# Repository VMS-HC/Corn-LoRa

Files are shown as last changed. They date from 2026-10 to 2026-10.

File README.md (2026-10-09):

<p align="left">
  Moving Rainbow Gradient Text
</p>
A not so basic electronic project... This is a LoRa Board which is great for meshtastic but not great for my sanity when routing! This has a SX1262 radio chip and uses a RP2040 for the microcontroller along with a crystal oscillator for the RP2040 like any normal dev board. Corn LoRa also includes a *0900FM15D0039* as a IPD (integrated passive device) by Johanson which controls the balun and filtering (868-915MHz, may be different footprint) To switch between TX and RX, it uses an RF switch, controlled by DIO2; along with a PE4259 for a 2 channel switcher (as mentioned above!). It also uses a bulky non-standard Conn for an antenna! 
Ty for looking and have a good day! <3!
# Corn-LoRa PCB photo!
 3D Render photo!
 Schematic!

    

## FAQ

#### BOM?

There are 2 BOM technically one has the LCSC part numbers and the others is a quote from LCSC with links to parts too!

#### Is this good for beginners?

Yes and no, if you know EDA/Kicad basics and could make a dev board without trouble you should be able to make this!

#### How many layers is the PCB?

This is a 4 layer PCB with a Earth layer and a +3V3 layer!

#### Can I contribute?

YES YOU CAN!!!! Take a peek at the Contributing section for a better guide on contributing!

## Authors

- [@bobert3d](https://www.github.com/Bobert3D)

- [@vms-hc](https://www.github.com/VMS-HC)

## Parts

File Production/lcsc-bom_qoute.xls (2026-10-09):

Corn LoRa |  |  |  |  |  |  |  |  |  | LCSC BOM Quotation
 |  |  |  |  |  |  |  |  |  | BOM Date Created：09/10/26 01:26:32 |  |  |  | BOM Export Date: 09/10/26 22:58:34 |  |  |  | The matching result is a real-time query result, availability and prices may fluctuate. Backorder items are estimated prices for your reference, please submit "Create Quote" to get the real price. All information is provided "as is" and is subject to change without notice. Any use made of the information provided is without recourse to LCSC and at the user's risk.
 |  |  |  |  |  |  |  |  |  | EST TOTAL :$22.09 |  |  |  | Website：https://www.lcsc.com/bom | https://www.lcsc.com/bom | https://www.lcsc.com/bom | https://www.lcsc.com/bom
Uploaded data |  |  |  |  |  |  |  |  |  | LCSC Matching Results
LCSC# | Mfr. | Mrf# | Description | Package | Value | Customer Part Number | Quantity | Target Price(USD) | Target Lead Time(Business Days) | Mrf# | Mfr. | Order Qty. | Unit Price(USD) | Ext.Price(USD) | LCSC# | Package | Min | Mult | SPQ | Availability | Stock Status | Customer Notes | Description | Matched status | Product Link
LCSC C276421 |  |  |  | Crystal_SMD_Abracon_ABM8G-4Pin_3.2x2.5mm |  | - | 1 |  |  | ABM8G-12.000MHZ-B4Y-T | ABRACON | 1 | 0.4560 | 0.46 | C276421 | SMD3225-4P | 1 | 1 | 1000 | 3622 | In Stock |  | Crystal 12MHz ±30ppm 10pF 120Ω SMD3225-4P | Partial Matches | https://www.lcsc.com/product-detail/C276421.html
LCSC |  |  |  | PinSocket_1x01_P2.54mm_Vertical |  |  | 1 |  |  | -(The data has been deleted.) | - | - | - | - | - | - | - | - | - | - | - | - | - | -
LCSC C2689642 |  |  |  | SW_Tactile_SPST_NO_Straight_CK_PTS636Sx25SMTRLFS |  | - | 1 |  |  | PTS636SK25SMTRLFS | C&K | 5 | 0.3565 | 1.78 | C2689642 | SMD,6x3.5mm | 5 | 5 | 3000 | 3045 | In Stock |  | Tactile Switch SPST-NO 250gf Gull Wing Surface Mount | Partial Matches | https://www.lcsc.com/product-detail/C2689642.html
LCSC C3951825 |  |  |  | R_0402_1005Metric |  | - | 2 |  |  | CRCW040227R4FKED | VISHAY | 50 | 0.0104 | 0.52 | C3951825 | 0402 | 50 | 50 | 10000 | 9650 | In Stock |  | 63mW 27.4Ω Thick Film Resistor ±100ppm/℃ ±1% 0402 Chip Resistor - Surface Mount RoHS | Partial Matches | https://www.lcsc.com/product-detail/C3951825.html
LCSC C327287 |  |  |  | C_0402_1005Metric |  | - | 3 |  |  | CC0402BRNPO9BN3R3 | YAGEO | 50 | 0.0084 | 0.42 | C327287 | 0402 | 50 | 50 | 10000 | 158500 | In Stock |  | 3.3pF 50V Ceramic Capacitor NP0 0402 | Partial Matches | https://www.lcsc.com/product-detail/C327287.html
LCSC C1525 |  |  |  | C_0402_1005Metric |  | - | 13 |  |  | CL05B104KO5NNNC | Samsung Electro-Mechanics | 100 | 0.0046 | 0.46 | C1525 | 0402 | 100 | 100 | 10000 | 102600 | In Stock |  | 100nF ±10% 16V Ceramic Capacitor X7R 0402 | Partial Matches | https://www.lcsc.com/product-detail/C1525.html
LCSC C60490 |  |  |  | R_0402_1005Metric |  | - | 1 |  |  | RC0402FR-0710KL | YAGEO | 100 | 0.0023 | 0.23 | C60490 | 0402 | 100 | 100 | 10000 | 4624300 | In Stock |  | 62.5mW 10kΩ 50V Thick Film Resistor ±100ppm/℃ ±1% 0402 Chip Resistor - Surface Mount RoHS | Partial Matches | https://www.lcsc.com/product-detail/C60490.html
LCSC C408132 |  |  |  | C_0402_1005Metric |  | - | 2 |  |  | GRM155R61A106ME11D | muRata | 20 | 0.0455 | 0.91 | C408132 | 0402 | 20 | 20 | 10000 | 280000 | In Stock |  | 10uF ±20% 10V Ceramic Capacitor X5R 0402 | Partial Matches | https://www.lcsc.com/product-detail/C408132.html
LCSC C191341 |  |  |  | QFN-24-1EP_4x4mm_P0.5mm_EP2.6x2.6mm |  | - | 1 |  |  | SX1262IMLTRT | SEMTECH | 1 | 3.2219 | 3.22 | C191341 | QFN-24-EP(4x4) | 1 | 1 | 3000 | 13955 | In Stock |  | 300Kbps -148dBm ISM 150MHz~960MHz 1.8V~3.7V QFN-24-EP(4x4) RF Transceiver ICs RoHS | Partial Matches | https://www.lcsc.com/product-detail/C191341.html
LCSC C2988369 |  |  |  | USB_C_Receptacle_GCT_USB4105-xx-A_16P_TopMnt_Horizontal |  | - | 1 |  |  | GT-USB-7010ASV | G-Switch | 5 | 0.0839 | 0.42 | C2988369 | SMD | 5 | 5 | 1000 | 87620 | In Stock |  | USB-C (USB TYPE-C) Receptacle Connector 16 Position Surface Mount, Right Angle | Partial Matches | https://www.lcsc.com/product-detail/C2988369.html
LCSC C106235 |  |  |  | R_0402_1005Metric |  | - | 2 |  |  | RC0402FR-071KL | YAGEO | 100 | 0.0038 | 0.38 | C106235 | 0402 | 100 | 100 | 10000 | 1131800 | In Stock |  | 1kΩ 62.5mW 50V Thick Film Resistor ±100ppm/℃ ±1% 0402 Chip Resistor - Surface Mount RoHS | Partial Matches | https://www.lcsc.com/product-detail/C106235.html
LCSC C383402 |  |  |  | L_0805_2012Metric_Pad1.15x1.40mm_HandSolder |  | - | 1 |  |  | MLZ2012M150WT000 | TDK | 10 | 0.0745 | 0.75 | C383402 | 0805 | 10 | 10 | 2000 | 32740 | In Stock |  | 250mA 15uH ±20% 120mA 950mΩ Multilayer inductor 0805 Fixed Inductors RoHS | Partial Matches | https://www.lcsc.com/product-detail/C383402.html
LCSC C105872 |  |  |  | R_0402_1005Metric |  | - | 2 |  |  | RC0402FR-075K1L | YAGEO | 100 | 0.0025 | 0.25 | C105872 | 0402 | 100 | 100 | 10000 | 2123800 | In Stock |  | 5.1kΩ 62.5mW 50V Thick Film Resistor ±100ppm/℃ ±1% 0402 Chip Resistor - Surface Mount RoHS | Partial Matches | https://www.lcsc.com/product-detail/C105872.html
LCSC C29266 |  |  |  | C_0402_1005Metric |  | - | 2 |  |  | CL05A105KO5NNNC | Samsung Electro-Mechanics | 50 | 0.0076 | 0.38 | C29266 | 0402 | 50 | 50 | 10000 | 1336100 | In Stock |  | 1uF ±10% 16V Ceramic Capacitor X5R 0402 | Partial Matches | https://www.lcsc.com/product-detail/C29266.html
LCSC C113767 |  |  |  | SOIC-8_5.3x5.3mm_P1.27mm |  | - | 1 |  |  | W25Q128JVSIQ | Winbond | 1 | 2.5196 | 2.52 | C113767 | SOIC-8-208mil | 1 | 1 | 90 | 7241 | In Stock |  | 128Mbit 2.7V~3.6V 133MHz SPI SOIC-8-208mil Memory RoHS | Partial Matches | https://www.lcsc.com/product-detail/C113767.html
LCSC C23380830 |  |  |  | SOT-23-5 |  | - | 1 |  |  | AP2112K-3.3TRG1 | TECH PUBLIC | 5 | 0.1113 | 0.56 | C23380830 | SOT-23-5 | 5 | 5 | 3000 | 2250 | In Stock |  | 3.3V Positive Fixed SOT-23-5 Voltage Regulators - Linear, Low Drop Out (LDO) Regulators | Partial Matches | https://www.lcsc.com/product-detail/C23380830.html
LCSC C470892 |  |  |  | SOT-363_SC-70-6 |  | - | 1 |  |  | PE4259-63 | pSemi | 1 | 1.1563 | 1.16 | C470892 | SC-70-6 | 1 | 1 | 3000 | 3498 | In Stock |  | 10MHz~3GHz SC-70-6 RF Switches RoHS | Partial Matches | https://www.lcsc.com/product-detail/C470892.html
LCSC C441742 |  |  |  | C_0402_1005Metric |  | - | 2 |  |  | GJM1555C1H150FB01D | muRata | 50 | 0.0241 | 1.21 | C441742 | 0402 | 50 | 50 | 10000 | 298650 | In Stock |  | 15pF ±1% 50V Ceramic Capacitor C0G 0402 | Partial Matches | https://www.lcsc.com/product-detail/C441742.html
LCSC C880605 |  |  |  | C_0402_1005Metric |  | - | 2 |  |  | TCC0402X7R473K500AT | CCTC | 50 | 0.0029 | 0.15 | C880605 | 0402 | 50 | 50 | 10000 | 1505350 | In Stock |  | 47nF ±10% 50V Ceramic Capacitor X7R 0402 | Partial Matches | https://www.lcsc.com/product-detail/C880605.html
LCSC C85815 |  |  |  | L_0402_1005Metric |  | - | 1 |  |  | BLM15AX102SN1D | muRata | 100 | 0.0112 | 1.12 | C85815 | 0402 | 100 | 100 | 10000 | 98600 | In Stock |  | 1kΩ@100MHz 1 Line Ferrite Bead 0402 350mA 490mΩ | Partial Matches | https://www.lcsc.com/product-detail/C85815.html
LCSC C7434807 |  |  |  | Balun_Johanson_0900FM15K0039 |  | - | 1 |  |  | 0900FM15K0039001E | Johanson Dielectrics | 1 | 0.9819 | 0.98 | C7434807 | 0805 | 1 | 1 | 4000 | 382 | In Stock |  | 1.1dB 862MHz~928MHz 0805 Ceramic Filters RoHS | Partial Matches | https://www.lcsc.com/product-detail/C7434807.html
LCSC C14442 |  |  |  | C_0402_1005Metric |  | - | 1 |  |  | CL05B102KB5NNNC | Samsung Electro-Mechanics | 100 | 0.0044 | 0.44 | C14442 | 0402 | 100 | 100 | 10000 | 1821700 | In Stock |  | 1nF ±10% 50V Ceramic Capacitor X7R 0402 | Partial Matches | https://www.lcsc.com/product-detail/C14442.html
LCSC C2040 |  |  |  | QFN-56-1EP_7x7mm_P0.4mm_EP3.2x3.2mm |  | - | 1 |  |  | RP2040 | Raspberry Pi | 1 | 0.9975 | 1.00 | C2040 | LQFN-56(7x7) | 1 | 1 | 3400 | 53257 | In Stock |  | ARM Cortex-M0+ 32 Bit 133MHz LQFN-56(7x7) Microcontrollers | Partial Matches | https://www.lcsc.com/product-detail/C2040.html
LCSC C2689642 |  |  |  | SW_Tactile_SPST_NO_Straight_CK_PTS636Sx25SMTRLFS |  |  | 1 |  |  | -(The data has been deleted.) | - | - | - | - | - | - | - | - | - | - | - | - | - | -
LCSC C162547 |  |  |  | L_0402_1005Metric |  | - | 1 |  |  | LQG15HS9N1J02D | muRata | 50 | 0.0190 | 0.95 | C162547 | 0402 | 50 | 50 | 10000 | 462950 | In Stock |  | 500mA 9.1nH ±5% 260mΩ Multilayer inductor 0402 Fixed Inductors RoHS | Partial Matches | https://www.lcsc.com/product-detail/C162547.html
LCSC C7275126 |  |  |  | Crystal_SMD_3225-4Pin_3.2x2.5mm |  | - | 1 |  |  | HY32MSMD3225EB1R30 | Huiyuan crystal | 10 | 0.0663 | 0.66 | C7275126 | SMD3225-4P | 10 | 10 | 3000 | 2440 | In Stock |  | Crystal 32MHz 10pF 40Ω SMD3225-4P | Partial Matches | https://www.lcsc.com/product-detail/C7275126.html
LCSC C2906884 |  |  |  | R_0402_1005Metric |  | - | 1 |  |  | FRC0402J101 TS | FOJAN | 100 | 0.0012 | 0.12 | C2906884 | 0402 | 100 | 100 | 10000 | 3792600 | In Stock |  | 100Ω ±5% 62.5mW 0402 Thick Film Resistor | Partial Matches | https://www.lcsc.com/product-detail/C2906884.html
LCSC C106223 |  |  |  | C_0402_1005Metric |  | - | 1 |  |  | CC0402JRNPO9BN390 | YAGEO | 100 | 0.0047 | 0.47 | C106223 | 0402 | 100 | 100 | 10000 | 195000 | In Stock |  | 39pF ±5% 50V Ceramic Capacitor NP0 0402 | Partial Matches | https://www.lcsc.com/product-detail/C106223.html
LCSC C47339 |  |  |  | C_0402_1005Metric |  | - | 1 |  |  | CL05A474KP5NNNC | Samsung Electro-Mechanics | 50 | 0.0113 | 0.57 | C47339 | 0402 | 50 | 50 | 10000 | 173350 | In Stock |  | 470nF ±10% 10V Ceramic Capacitor X5R 0402 | Partial Matches | https://www.lcsc.com/product-detail/C47339.html
TBD |  |  |  | U.FL_Molex_MCRF_73412-0110_Vertical |  |  | 1 |  |  | -(The data has been deleted.) | - | - | - | - | - | - | - | - | - | - | - | - | - | -

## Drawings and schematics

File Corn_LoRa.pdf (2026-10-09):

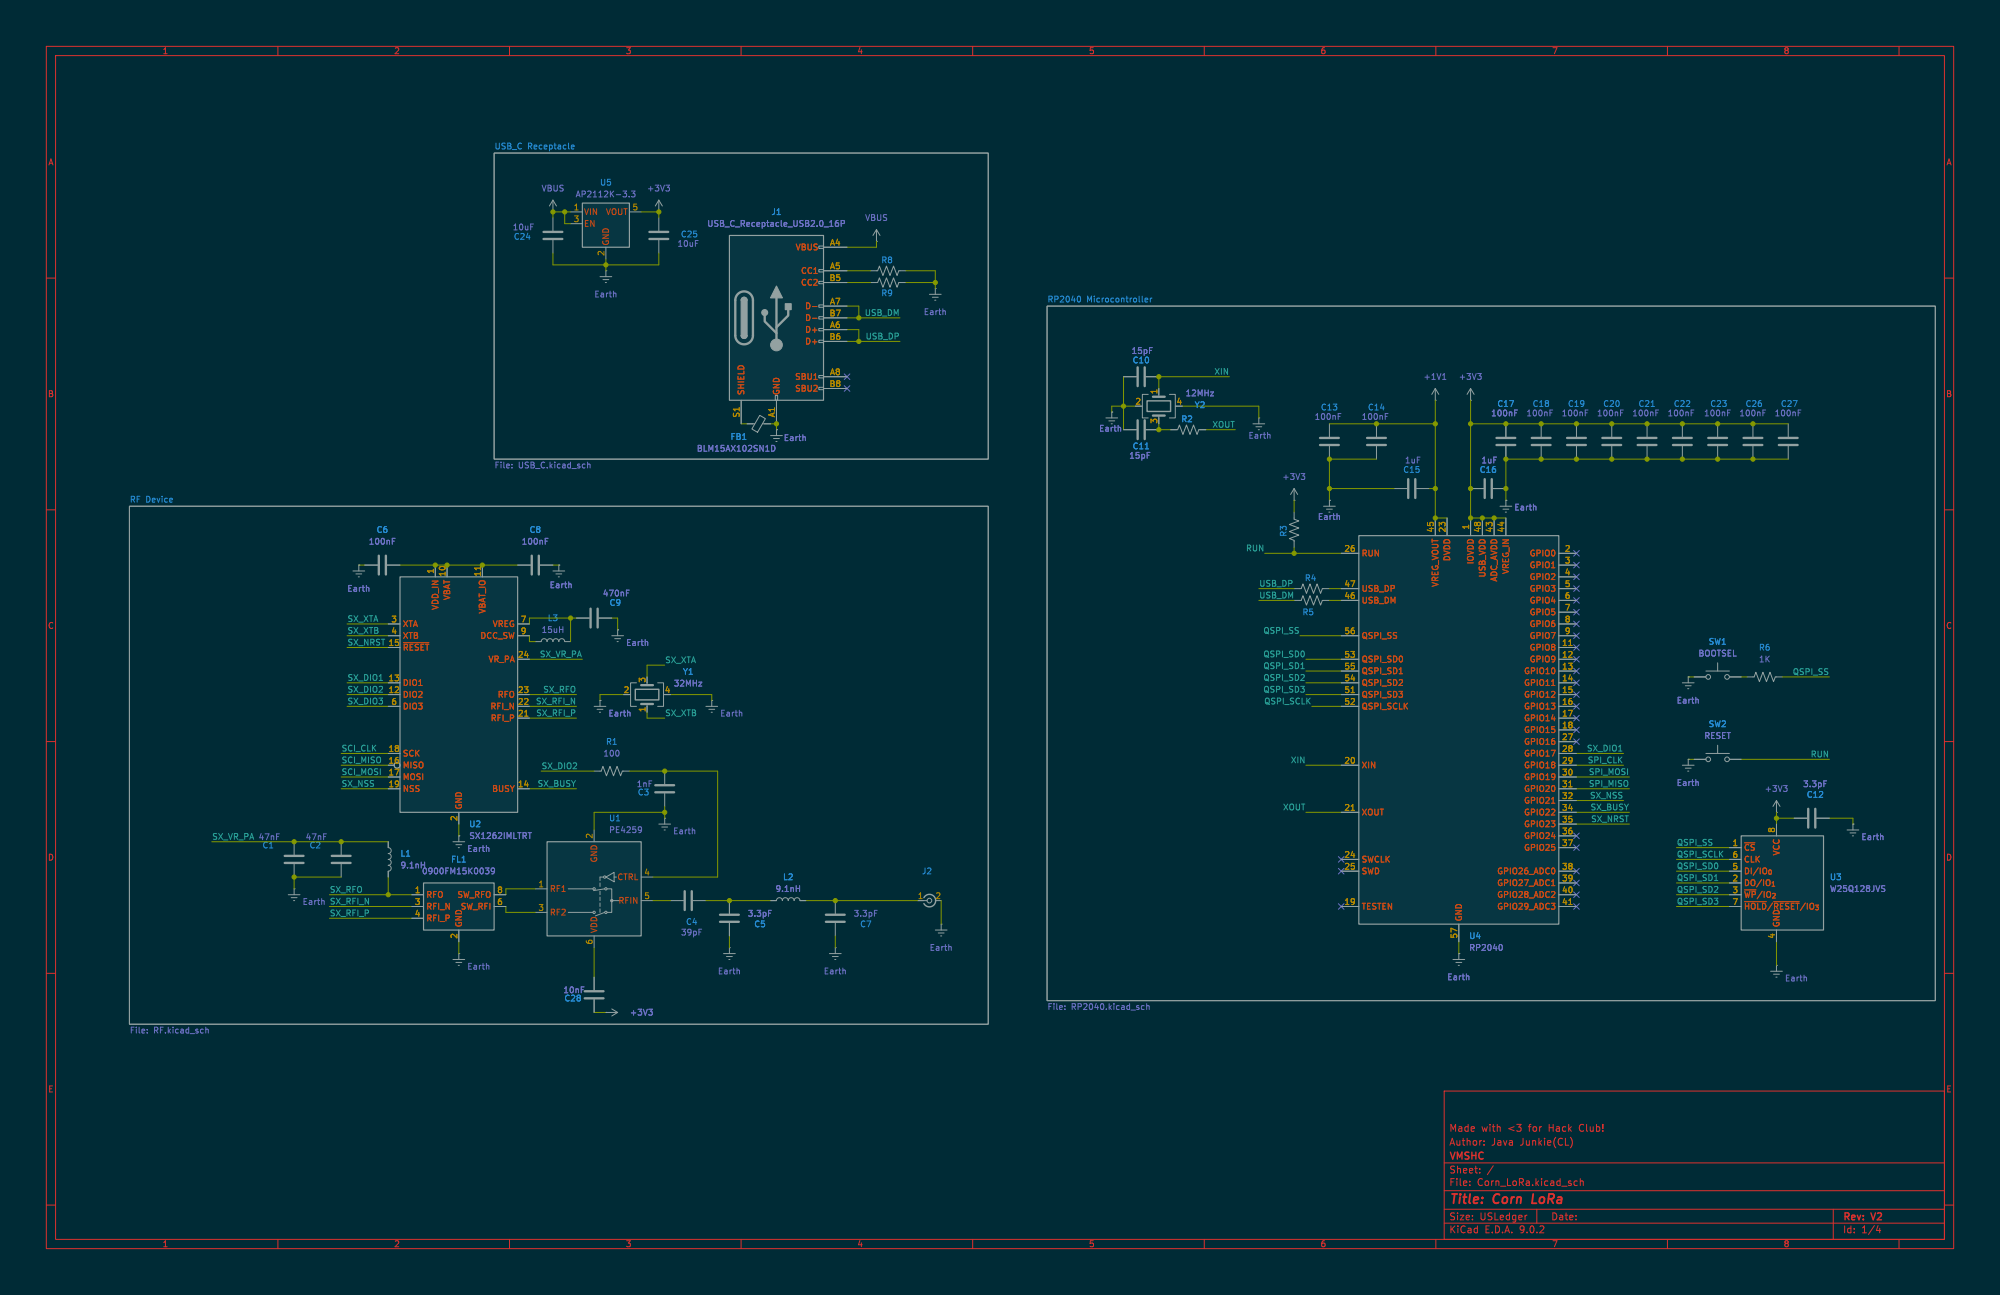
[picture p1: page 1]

1 USB_VDD 48 ADC_AVDD 43 VREG_IN 44 GPIO0 2 GPIO1 3 GPIO2 4 GPIO3 5 GPIO4 6 GPIO5 7 GPIO6 8 GPIO7 9 GPIO8 11 GPIO9 12 GPIO10 13 GPIO11 14 GPIO12 15 GPIO13 16 GPIO14 17 GPIO15 18 GPIO16 27 GPIO17 28 GPIO18 29 GPIO19 30 GPIO20 31 GPIO21 32 GPIO22 34 GPIO23 35 GPIO24 36 GPIO25 37 GPIO26_ADC0 38 GPIO27_ADC1 39 GPIO28_ADC2 40 GPIO29_ADC3 41 Earth Earth SW2 RESET SW1 BOOTSEL Earth C10

2 SW_RFO 8 SW_RFI 6 U2SX1262IMLTRT XTA 3 XTB 4 ~{RESET} 15 DIO1 13 DIO2 12 DIO3 6 SCK 18 MISO 16 MOSI 17 NSS 19 VDD_IN

Id: 1/4 Title: Corn LoRa

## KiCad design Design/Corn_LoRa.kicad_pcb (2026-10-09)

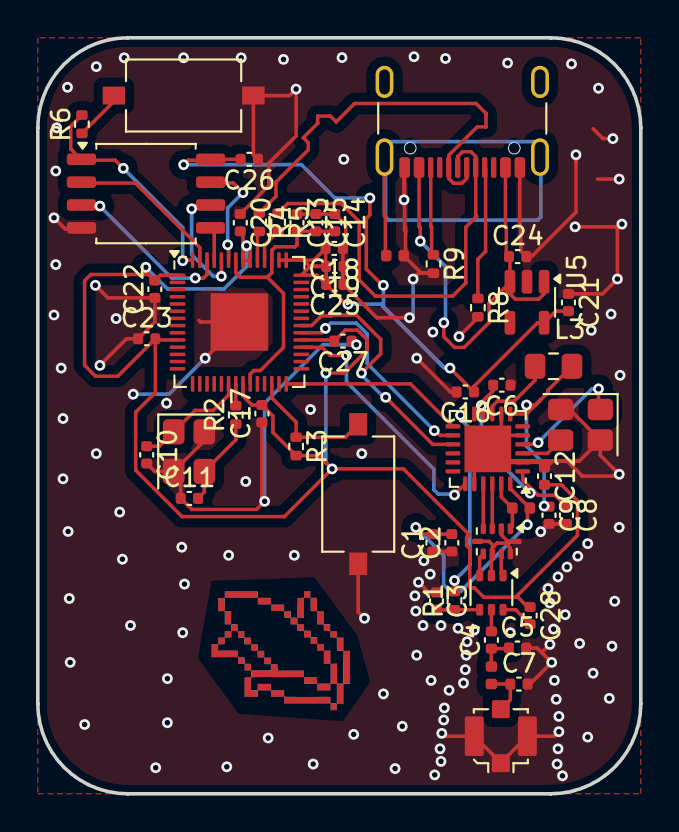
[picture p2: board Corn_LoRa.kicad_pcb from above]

Board: 4 copper layers, 33.5 x 42.0 mm, 52 parts (0 on the bottom side), 43 nets.

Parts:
C1, C2: 47nF; C_0402_1005Metric
C3: 1nF; C_0402_1005Metric
C4: 39pF; C_0402_1005Metric
C5, C7, C12: 3.3pF; C_0402_1005Metric
C6, C8, C13, C14, C17, C18, C19, C20, C21, C22, C23, C26, C27: 100nF; C_0402_1005Metric
C9: 470nF; C_0402_1005Metric
C10, C11: 15pF; C_0402_1005Metric
C15, C16: 1uF; C_0402_1005Metric
C24, C25: 10uF; C_0402_1005Metric
C28: 10nF; C_0402_1005Metric
FB1: BLM15AX102SN1D; L_0402_1005Metric
FL1: 0900FM15K0039; Balun_Johanson_0900FM15K0039
J1: USB_C_Receptacle_USB2.0_16P; USB_C_Receptacle_GCT_USB4105-xx-A_16P_TopMnt_Horizontal
J2: Conn_Coaxial_Small; U.FL_Molex_MCRF_73412-0110_Vertical
L1, L2: 9.1nH; L_0402_1005Metric
L3: 15uH; L_0805_2012Metric_Pad1.15x1.40mm_HandSolder
R1: 100; R_0402_1005Metric
R2, R6: 1K; R_0402_1005Metric
R3: 10K; R_0402_1005Metric
R4, R5: 27.4; R_0402_1005Metric
R8, R9: 5.1K; R_0402_1005Metric
SW1: BOOTSEL; SW_Tactile_SPST_NO_Straight_CK_PTS636Sx25SMTRLFS
SW2: RESET; SW_Tactile_SPST_NO_Straight_CK_PTS636Sx25SMTRLFS
U1: PE4259; SOT-363_SC-70-6
U2: SX1262IMLTRT; QFN-24-1EP_4x4mm_P0.5mm_EP2.6x2.6mm
U3: W25Q128JVS; SOIC-8_5.3x5.3mm_P1.27mm
U4: RP2040; QFN-56-1EP_7x7mm_P0.4mm_EP3.2x3.2mm
U5: AP2112K-3.3; SOT-23-5
Y1: 32MHz; Crystal_SMD_3225-4Pin_3.2x2.5mm
Y2: 12MHz; Crystal_SMD_Abracon_ABM8G-4Pin_3.2x2.5mm

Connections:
+1V1: C13.2, C14.2, C15.2, U4.23 (DVDD), U4.45 (VREG_VOUT), U4.50 (DVDD)
+3V3: C12.2, C16.1, C17.2, C18.2, C19.2, C20.2, C21.2, C22.2, C23.2, C25.2, C26.2, C27.2, C28.1, R3.2, U3.8 (VCC), U4.1 (IOVDD), U4.10 (IOVDD), U4.22 (IOVDD), U4.33 (IOVDD), U4.42 (IOVDD), U4.43 (ADC_AVDD), U4.44 (VREG_IN), U4.48 (USB_VDD), U4.49 (IOVDD), U5.5 (VOUT)
/QSPI_SCLK: U3.6 (CLK), U4.52 (QSPI_SCLK)
/QSPI_SD0: U3.5 (DI/IO_{0}), U4.53 (QSPI_SD0)
/QSPI_SD1: U3.2 (DO/IO_{1}), U4.55 (QSPI_SD1)
/QSPI_SD2: U3.3 (~WP/IO_{2}), U4.54 (QSPI_SD2)
/QSPI_SD3: U3.7 (~HOLD/~RESET/IO_{3}), U4.51 (QSPI_SD3)
/QSPI_SS: R6.2, U3.1 (~CS), U4.56 (QSPI_SS)
/RUN: R3.1, SW2.2, U4.26 (RUN)
/SX_BUSY: U2.14 (BUSY), U4.34 (GPIO22)
/SX_DIO1: U2.13 (DIO1), U4.28 (GPIO17)
/SX_DIO2: R1.2, U2.12 (DIO2)
/SX_NRST: U2.15 (~RESET), U4.35 (GPIO23)
/SX_NSS: U2.19 (NSS), U4.32 (GPIO21)
/SX_RFI_N: FL1.3 (RFI_N), U2.22 (RFI_N)
/SX_RFI_P: FL1.4 (RFI_P), U2.21 (RFI_P)
/SX_RFO: FL1.1 (RFO), L1.2, U2.23 (RFO)
/SX_VR_PA: C1.2, C2.2, L1.1, U2.24 (VR_PA)
/SX_XTA: U2.3 (XTA), Y1.3
/SX_XTB: U2.4 (XTB), Y1.1
/USB_DM: J1.A7 (D-), J1.B7 (D-), R5.1
/USB_DP: J1.A6 (D+), J1.B6 (D+), R4.1
/XIN: C10.1, U4.20 (XIN), Y2.1
/XOUT: R2.2, U4.21 (XOUT)
Earth: C1.1, C2.1, C3.1, C5.2, C6.1, C7.2, C8.2, C9.2, C10.2, C11.1, C12.1, C13.1, C14.1, C15.1, C16.2, C17.1, C18.1, C19.1, C20.1, C21.1, C22.1, C23.1, C24.2, C25.1, C26.1, C27.1, FB1.2, FL1.2 (GND), FL1.5 (GND), FL1.7 (GND), FL1.9 (GND), FL1.10 (GND), J1.A1 (GND), J1.A12 (GND), J1.B1 (GND), J1.B12 (GND), J2.2 (Ext), R8.2, R9.2, SW1.1, SW2.1, U1.2 (GND), U2.2 (GND), U2.5 (GND), U2.8 (GND), U2.20 (GND), U2.25 (GND), U3.4 (GND), U4.57 (GND), U5.2 (GND), Y1.2, Y1.4, Y2.2, Y2.4
unnamed: C4.1, C5.1, L2.1
unnamed: C11.2, R2.1, Y2.3
unnamed: FL1.6 (SW_RFI), U1.3 (RF2)
unnamed: FL1.8 (SW_RFO), U1.1 (RF1)
unnamed: J1.A5 (CC1), R8.1
unnamed: J1.B5 (CC2), R9.1
unnamed: FB1.1, J1.S1 (SHIELD)
unnamed: C7.1, J2.1 (In), L2.2
unnamed: R6.1, SW1.2
unnamed: C3.2, R1.1, U1.4 (CTRL)
unnamed: C4.2, U1.5 (RFIN)
unnamed: C28.2, U1.6 (VDD)
unnamed: L3.1, U2.9 (DCC_SW)
unnamed: C6.2, C8.1, U2.1 (VDD_IN), U2.10 (VBAT), U2.11 (VBAT_IO)
unnamed: C9.1, L3.2, U2.7 (VREG)
unnamed: R5.2, U4.46 (USB_DM)
unnamed: R4.2, U4.47 (USB_DP)
VBUS: C24.1, J1.A4 (VBUS), J1.A9 (VBUS), J1.B4 (VBUS), J1.B9 (VBUS), U5.1 (VIN), U5.3 (EN)

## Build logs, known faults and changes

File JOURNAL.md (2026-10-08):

---
title: "Corn LoRa!"
github: "https://github.com/VMS-HC/Corn-LoRa/tree/main"
description: "A LoRa puck of the corn series!!! This was just a lets do something a little harder but it was very fun! Thanks!"
created_at: "2026-10-03"
total_time: "5h 30m"
---

# October 3, 2026: A TONNN!!!!! OF WORK!!!

SO! I did a 2 ish (more lol) session at my makerspace and locked in for kicad and I got almost the entire PCB done before routing!!!! Im sooo close lol and I cant wait! TYSM!

<3!

Timelapse: https://lapse.hackclub.com/timelapse/5QtBMyAMPZ38

**Total time spent: 2h 12m**

# October 3, 2026: Started the schematic!!!

I started the schematic and added the main parts lol but I realized I need to get more organized so I redid the schematic and now Its good!!! Also I forgot to do this one before the PCB starting one lol but idk!



Timelapse: https://lapse.hackclub.com/timelapse/7STcW7NEFYpA

**Total time spent: 1h 12m**

# October 3, 2026: More placement and movement of footprints!...:3

So I continued to move some stuff and fix the placement of a few footprints but I couldn't figure out which ones went where so I stopped and cried but pushed through and I only have 3 footprints left before I'm going to start routing!!!!


my sadness >3

Timelapse: https://lapse.hackclub.com/timelapse/5mFJXgL974Ie

**Total time spent: 24m**

# October 4, 2026: death to part

So I continued to setup the PCB and I'm finally done!!!! but... I have these 2 DRC errors that say something along the lines of fu top and inu aren't connected and same for fu top and bu bottom???? what pls help lol ai is useless and I cant fix it with vias lol?? I also fixed the majority of the first DRC so its only the 2 now.










Timelapse: https://lapse.hackclub.com/timelapse/IK4pxGH8sZ_W

**Total time spent: 1h 42m**

# October 7, 2026: BOM time!!

I continued the Bom links to LCSC and that kind of thing but then I found out they don’t make 15uH inductors at 0402-1005 metric size so I changed my pcb and schematic to 8012 I think that’s the right size name idk something like that and I did drc and then finally exported the new and fixed files and gerbers and drill files along with the new Bom and pos 

Timelapse: https://lapse.hackclub.com/timelapse/2xBPIhkcMYNh

**Total time spent: 37m**

**Total time spent: 1h 42m**

# October 8, 2026: Fixing BOM and adding files to repo!

I continued the Bom links to LCSC AGAIN!!! and I had to check the schematic and PCB a few times but otherwise easy and smooth sailing and I had a weird deal with my cart having 26 parts and my BOM having 28 or 29 but I fixed it and exported my fixed BOM from LCSC quote/BOM maker and I'm good and I'm going to ship and hope it gets approved!!!! TYSM! <3


Timelapse: https://lapse.hackclub.com/timelapse/UgbOoN_d3eiA

**Total time spent: 50m**

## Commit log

2026-10-04 Add contribution guidelines to CONTRIBUTING.md
    Added contribution guidelines for Hack Club repositories, covering GitHub flow, branch and file naming conventions, commit standards, and pull request creation.
2026-10-04 PCB and Kicad files
    [Corn_LoRafinal.kicad_pcb]
2026-10-05 Added BOM
    [Corn_LoRa.csv]
2026-10-05 added pos files
    [Corn_LoRa-bottom-pos.csv, Corn_LoRa-top-pos.csv]
2026-10-07 Create journal for Corn LoRa project progress
    Added journal entries documenting progress on the Corn LoRa project, including schematic setup and PCB design.
2026-10-07 Add journal entry for October 4, 2026
    Updated journal entry for October 4, 2026, detailing changes to PCB and schematic.
2026-10-08 Added gerbers
2026-10-08 Rename Gerber-LoRa (1).zip to Gerber-LoRa.zip
2026-10-08 Delete Production/Corn_LoRa-bottom-pos.csv
    No bottom pos needed
    [Corn_LoRa-bottom-pos.csv]
2026-10-08 Revise journal entry for October 8, 2026
    Updated journal entry for October 8, 2026, detailing BOM fixes and file additions.
2026-10-09 Added fixed gerbers again
2026-10-09 Rename Gerber-LoRa (2).zip to Gerber-LoRa-fixed.zip
2026-10-09 Added fixed pos
    [Corn_LoRa-all-pos.csv]
2026-10-09 Added correct BOM
    [Corn_LoRa - Corn_LoRa (2).csv, export_project_20261009_225834.xls]
2026-10-09 Rename Corn_LoRa - Corn_LoRa (2).csv to Corn_LoRa.csv
    [Corn_LoRa.csv]
2026-10-09 Added final fixed design files
    [Corn_LoRa.kicad_pcb]
2026-10-09 Update README with new images and schematic link
    Added additional images and a PDF link for the Corn-LoRa project.
2026-10-13 Added final BOM
2026-10-13 Add BOM.md with components and pricing details
    Added a bill of materials (BOM) with components, prices, and shipping details.
2026-10-13 Update PCB+Stencil price in BOM.md
2026-10-27 Revise journal entries and total time spent
    Updated total time spent and added entries with detailed progress on PCB design, schematic organization, and BOM adjustments.

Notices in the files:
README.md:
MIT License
